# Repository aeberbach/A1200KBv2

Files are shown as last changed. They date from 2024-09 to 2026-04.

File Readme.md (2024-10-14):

A few years ago I made my first Amiga 1200 mechanical keyboard. I did not know at the time about any other efforts that might be underway so I just went ahead and did it. It turned out well and a lot of people built them. Still, there is always a temptation to try and improve something. I was never really happy about the mounting system and the 9U spacebar was a problem, even more so than finding the keycaps that match the Amiga key sizes because modern keyboards went in a different direction.

So here is version 2. At the time of the last keyboard, low-profile keyswitches existed but were hard to find and often could not use MX-stem caps, now it is easier. I'm typing this with a Nuphy Air75 v2 with "Gateron x Nuphy Moss" KS-33 switches and the feel is amazing. There is a lighter variant "Wisteria" and a regular brown tactile option. Blue (clicky) and several variants of linear including red are available too. These switches use a different footprint to standard MX so the PCB had to be redone.

The low profile switches do not come in a 5-pin PCB mount version so a plate is essential. While laser-cut would be amazing I don't have a laser cutter, also that would not be 3-dimensional and would not leave space for the stabilizer wires. To keep it printable on common 3D printers there are multiple pieces to print. I have used eSun matte PLA, a good opaque material that is a good match for an A1200.net case in white or black. The stabilizers mount to the plates, the holes in the PCB underneath are only for clearance. These plates keep the keyswitches perfectly straight during assembly, improve keyboard stiffness, dampen sound and make for a better appearance.

Under the old keyboard a 10x3mm aluminium bar was used to stiffen the whole assembly, running from one side of the case to another sitting on 3d-printed mounts. I want to move that out of the way of expansions under the keyboard. I never noticed a problem with a TF1230 but with a larger accelerator having a heatsink it might be. There is plenty of room for a PiStorm32-lite, by far the fastest and most cost-effective accelerator today.

One thing that hasn't been done is to source a Caps Lock key with a window for the LED. The LED mount is still there and you can put a LED under the switch but I don't know where you can get a windowed keycap for it. The LED section of this keyboard includes a circuit where it will light an alternate LED for power when Caps Lock is active. My keybaord has a green LED for power but that changes to blue when Caps Lock is activated.

If you don't want to use the LED function of this keyboard you can just snip away the top right of the PCB and use the original Amiga 1200 LED PCB. In that case don't bother with LEDs, capacitor, resistors or the inverter chip.

Requirements:
- one PCB (see the 'fab' folder for gerber files, ready to build)
- 96 Gateron KS-33 keyswitches
- 5 Gateron 2U plate-mount low-profile stabilizers
- 1 more Gateron low-profile stabilizer to disassemble - bend your own wire from 1.0mm music wire, available from hobby stores.
- 0805 LEDs: red, green, yellow/orange and blue (or whatever colors you like for the various functions)
- 0805 current-limiting resistor for each LED. Choose a value not less than 300 ohms. If your LEDs are too bright you can use higher values. I found that 500-1k ohms is fine. Your LEDs may vary.
- 0.1uF 0805 decoupling capacitor
- SN74LVC2G04DBVR dual inverter (available Mouser electronics)
- 5-pin dupont housing, pins and ribbon cable to connect LED section to Amiga
- one FFC connector, 32-way RA 1.25mm pitch. Molex 52044-3245 (available Mouser Electronics) or look on AliExpress.
- one FFC ribbon cable, 31-way. Cut one connector from Molex 15168-0400 (available Mouser Electronics) or look on AliExpress.
- Printed left and right plates to house stabilizers and switches on top of PCB (STLs in 3dprint folder)
- Printed left, right and bottom mounts to secure the keyboard in your case (STLs in 3dprint folder)
- various M3 bolts or plastic rivets for assembly
- 96 Amiga keycaps: user Steveed on Amibay recently sorted this out with Signature Plastics and they are perfect. Seems expensive? Not until you spend hours looking for and buying various sets and never end up with a full set. 
 
The cost of all this varies with the cost of PCB manufacture, keyswitches and stabilizers and of course the keycaps. As a very rough guide expect to pay *no less* than about:
- PCB $20
- keyswitches $40
- stabilizers $20
- LEDs and other components $2
- FFC connector and cable $8
- 3D printed parts $10

And assembly will take at least three hours. That's just under $100 in parts alone and does not even count a quality set of keycaps at around $150. (But if you weren't slightly obsessed you probably wouldn't have an Amiga in 2024.)

The license for this keyboard is non-commercial. However if a person has ordered the minimum of 5 PCBs from one of the usual places and wants to offer the extras for sale at near cost that is reasonable.

Thanks to Steveed (Amibay) and to everyone that has supported this project. 

License: CC-BY-NC-SA 4.0

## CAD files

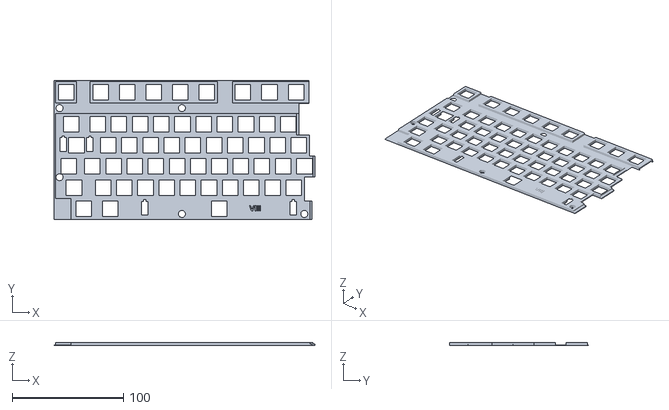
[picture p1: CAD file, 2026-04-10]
3dprint/Keyboard plates/Left Plate (VIII - no connector cut).stl
234.7 x 125.0 x 3.00

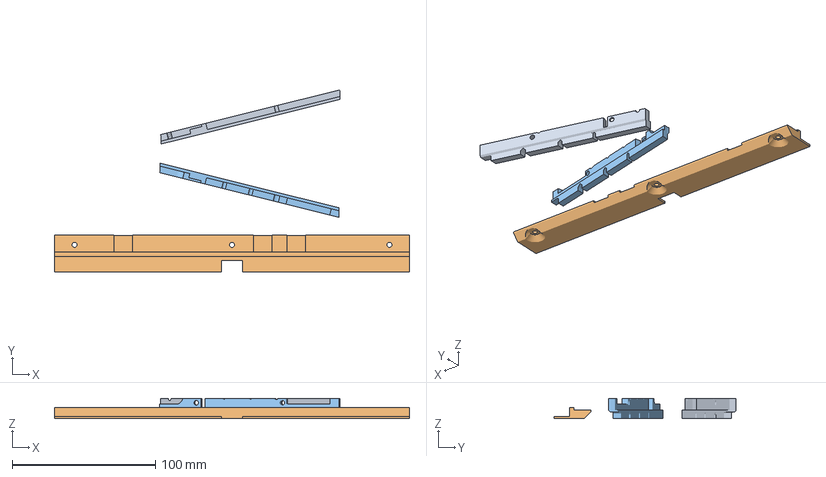
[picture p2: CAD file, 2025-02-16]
3dprint/Production/Prusa Slicer/Left Right Bottom mounts.3mf
248.0 x 127.2 x 14.0 mm
Left mount.stl
Lower mount.stl
Right mount.stl

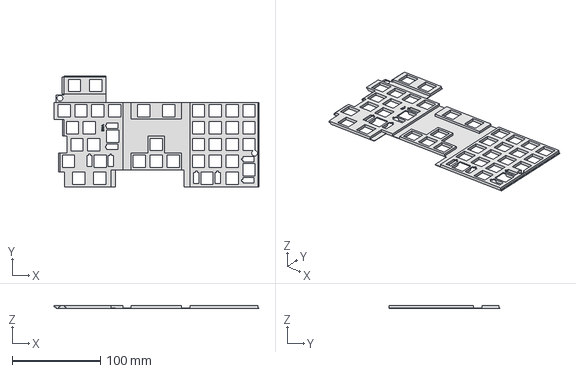
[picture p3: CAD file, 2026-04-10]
3dprint/STEP/Right Plate (VIII).stp
231.7 x 125.0 x 3.00 mm

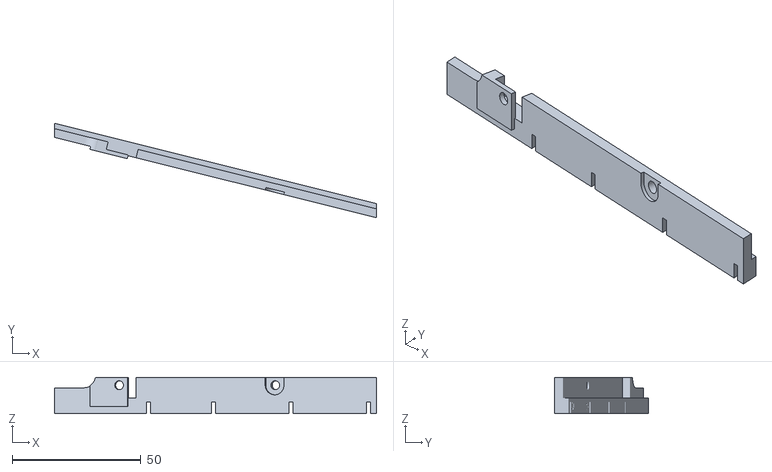
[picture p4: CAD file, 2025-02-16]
3dprint/Production/Commodore Right mount.stl
125.2 x 36.7 x 14.0

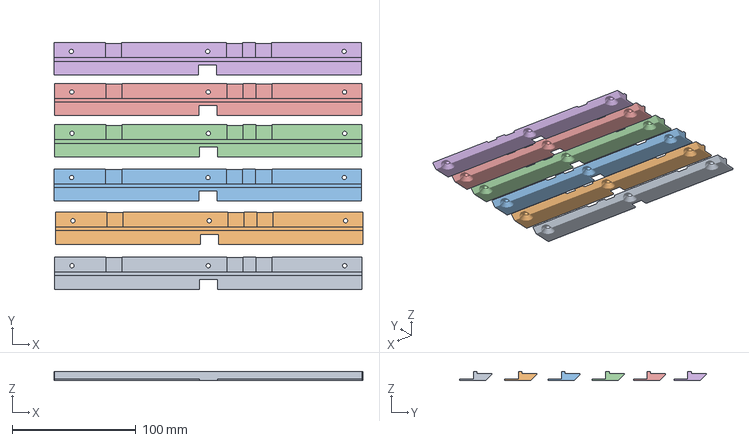
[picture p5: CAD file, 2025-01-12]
3dprint/Production/Prusa Slicer/6 x Lower mount no supports.3mf
249.2 x 198.9 x 7.60 mm

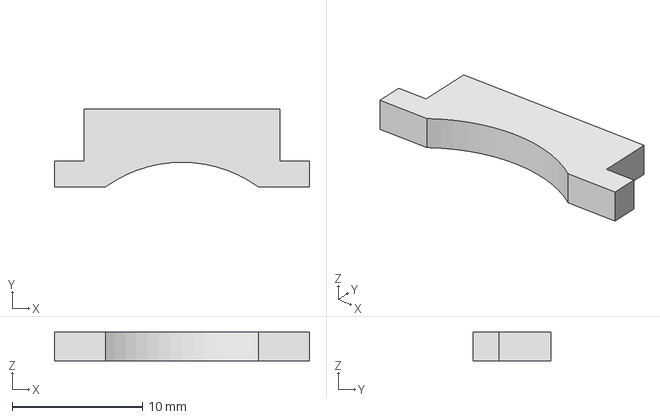
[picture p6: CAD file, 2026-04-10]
3dprint/STEP/Light Pipe A1200Net.stp
19.5 x 6.00 x 2.20 mm

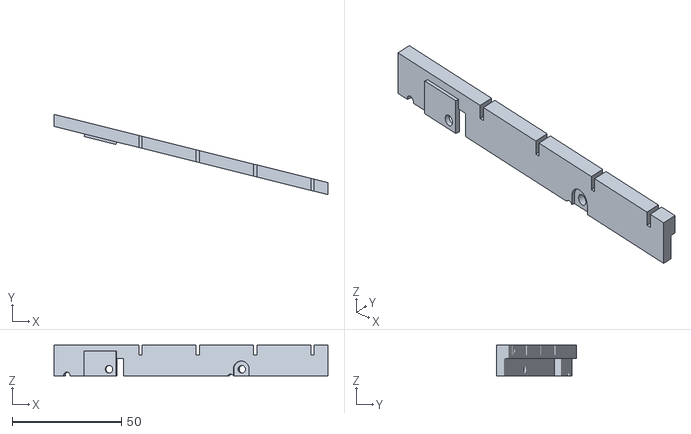
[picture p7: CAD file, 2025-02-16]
3dprint/Production/A1200net Left mount.stl
125.2 x 36.7 x 14.0

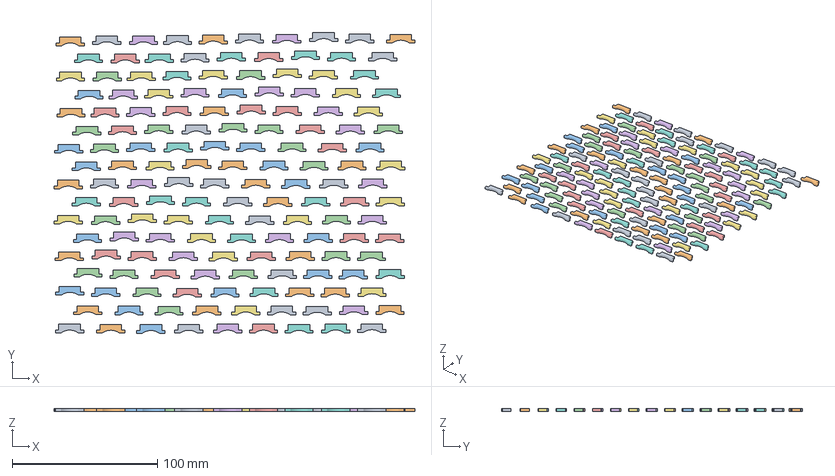
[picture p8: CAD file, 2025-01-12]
3dprint/Production/Prusa Slicer/Many Commodore Light Pipes.3mf
249.0 x 207.3 x 2.20 mm

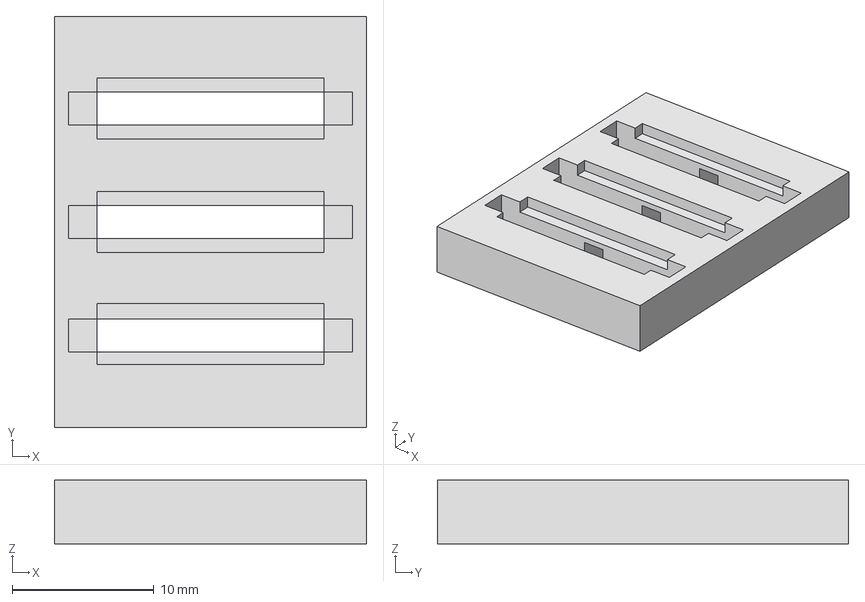
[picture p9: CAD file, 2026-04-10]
3dprint/STEP/Lightpipe shield A1200Net.stp
22.0 x 29.0 x 4.50 mm

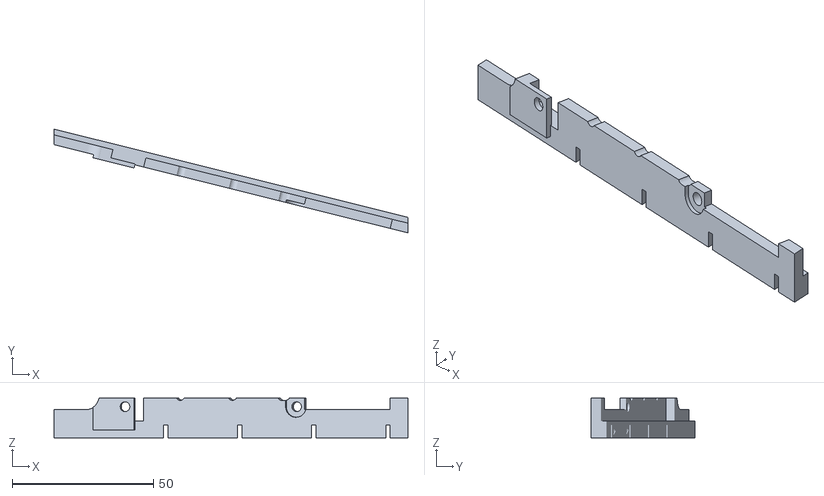
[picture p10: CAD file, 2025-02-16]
3dprint/Production/A1200net Right mount.stl
125.2 x 36.7 x 14.0

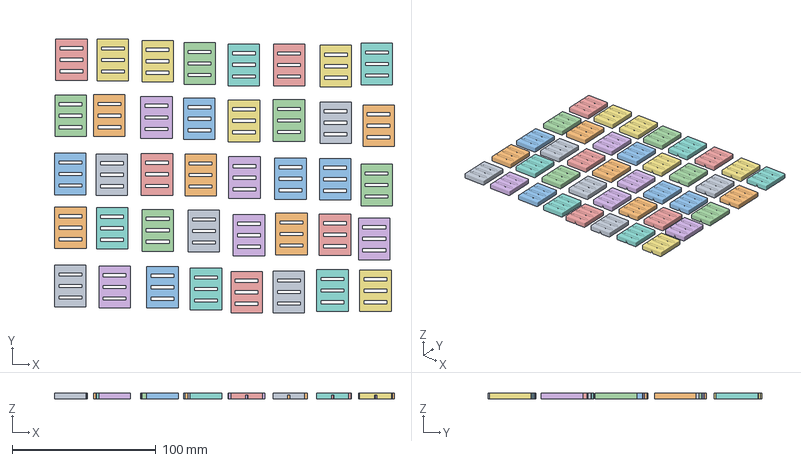
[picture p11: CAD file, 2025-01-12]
3dprint/Production/Prusa Slicer/20 each C= and A1200NET Lightpipe shield.3mf
236.2 x 190.4 x 4.50 mm
A1200NET Lightpipe shield.stl
C= Lightpipe shield.stl

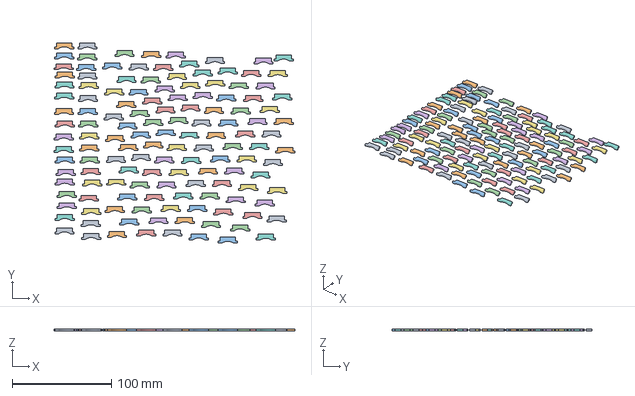
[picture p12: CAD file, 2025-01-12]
3dprint/Production/Prusa Slicer/Many A1200NET Light Pipes.3mf
243.3 x 202.3 x 2.20 mm
A1200NET Light Pipe.stl x 36

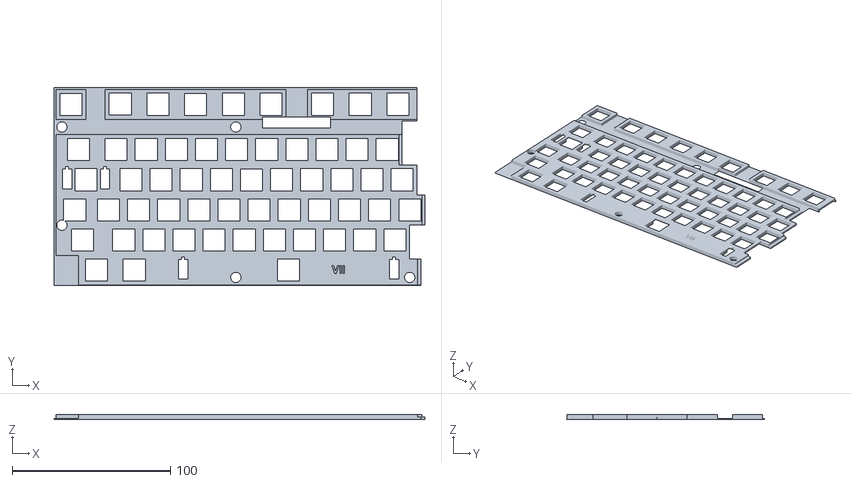
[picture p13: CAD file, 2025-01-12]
3dprint/Production/Common Left Plate (r7 - connector cut).stl
234.7 x 125.0 x 3.00

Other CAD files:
3dprint/Production/Common Left Plate (VIII - no connector cut).stl
3dprint/STEP/Left mount Commodore.stp
3dprint/Production/Commodore Left mount.stl
3dprint/STEP/Left mount A1200net.stp
3dprint/STEP/Right mount Commodore.stp
3dprint/A1200net/Light pipe/Light Pipe modern.ipt
3dprint/A1200net/Light pipe/Lightpipe shield.ipt
3dprint/A1200net/Mounting/A1200net Left mount.ipt
3dprint/A1200net/Mounting/A1200net Right mount.ipt
3dprint/Commodore/Light pipe/Light Pipe Commodore.ipt
3dprint/Commodore/Light pipe/Lightpipe shield.ipt
3dprint/Commodore/Mounting/Commodore Left mount.ipt
3dprint/Commodore/Mounting/Commodore Right mount.ipt
3dprint/Keyboard plates/A1200 Keyboard.iam
3dprint/Keyboard plates/Left Plate (VII - connector cut).ipt
3dprint/Keyboard plates/Left Plate (VIII - no connector cut).ipt
3dprint/Keyboard plates/Left Plate.ipt
3dprint/Keyboard plates/Right Plate.ipt
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

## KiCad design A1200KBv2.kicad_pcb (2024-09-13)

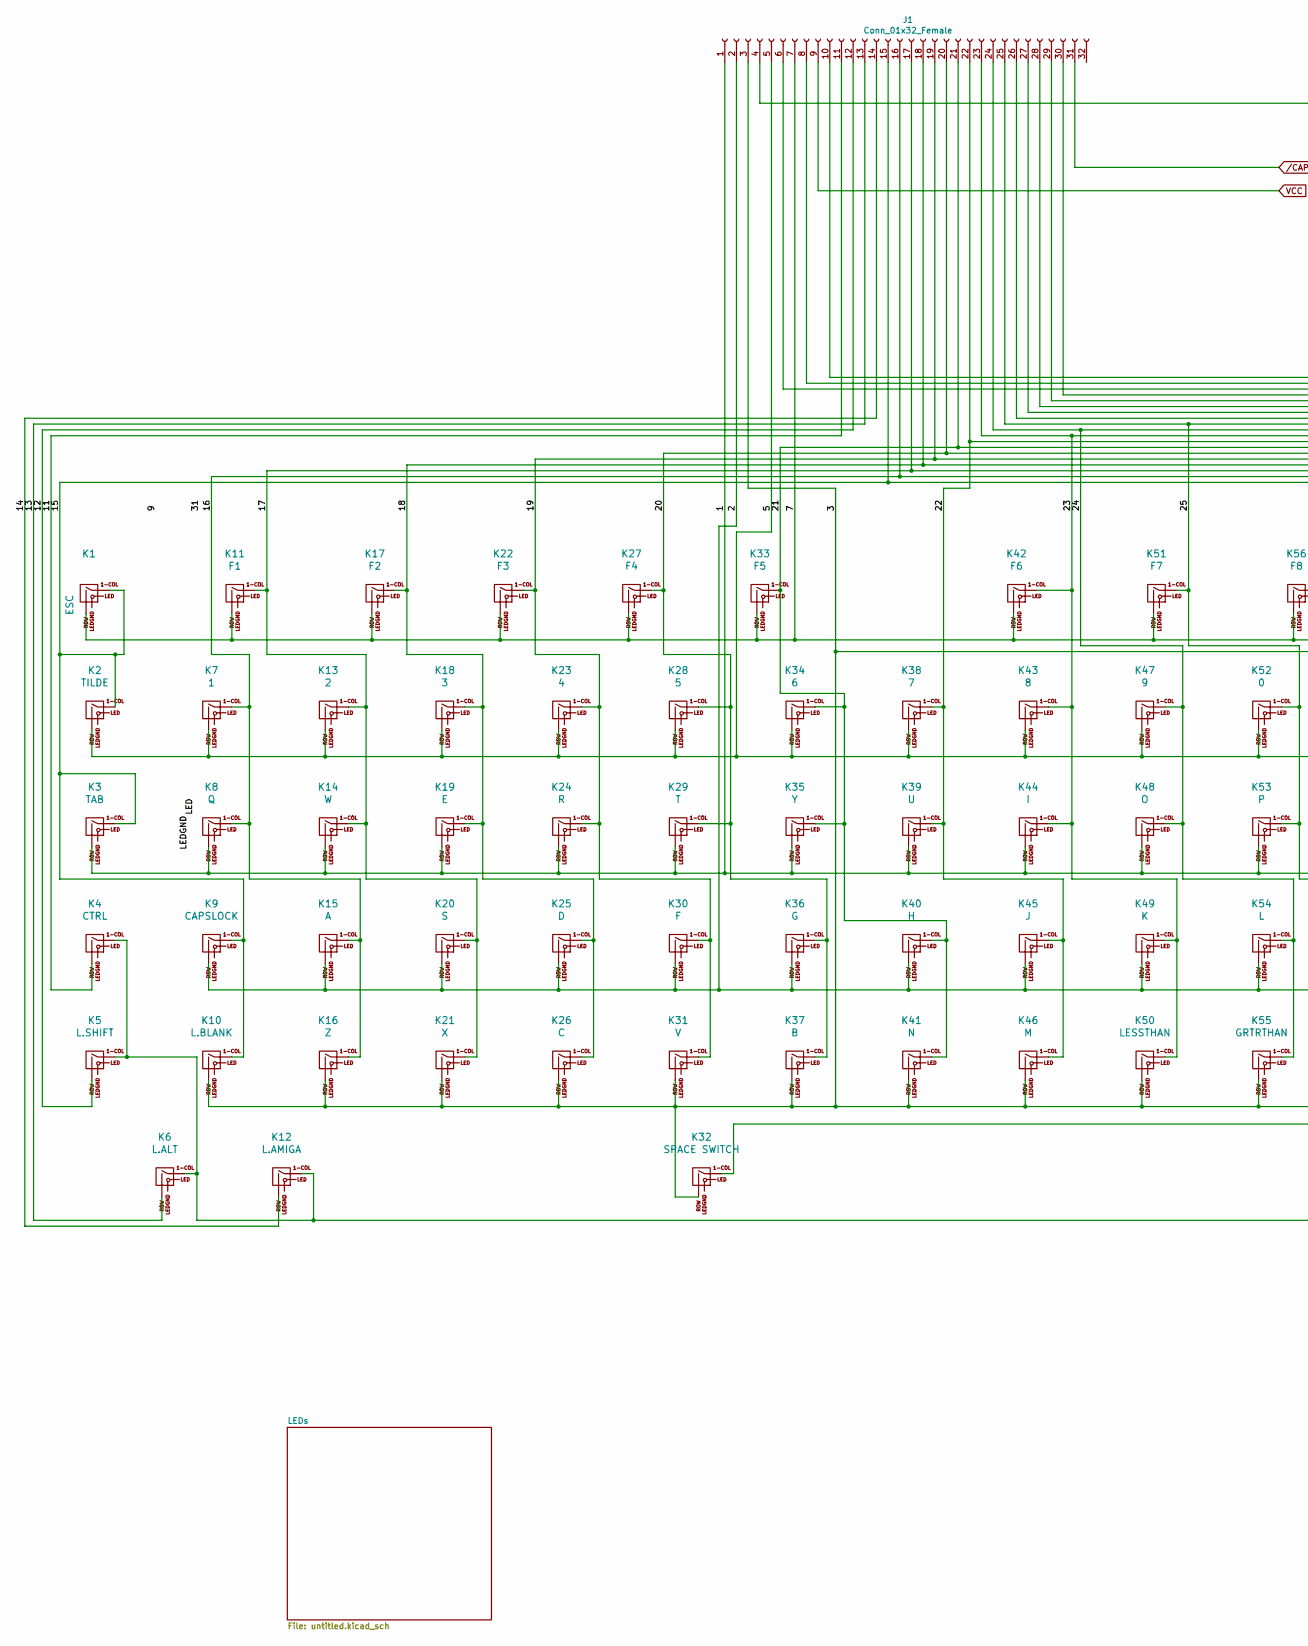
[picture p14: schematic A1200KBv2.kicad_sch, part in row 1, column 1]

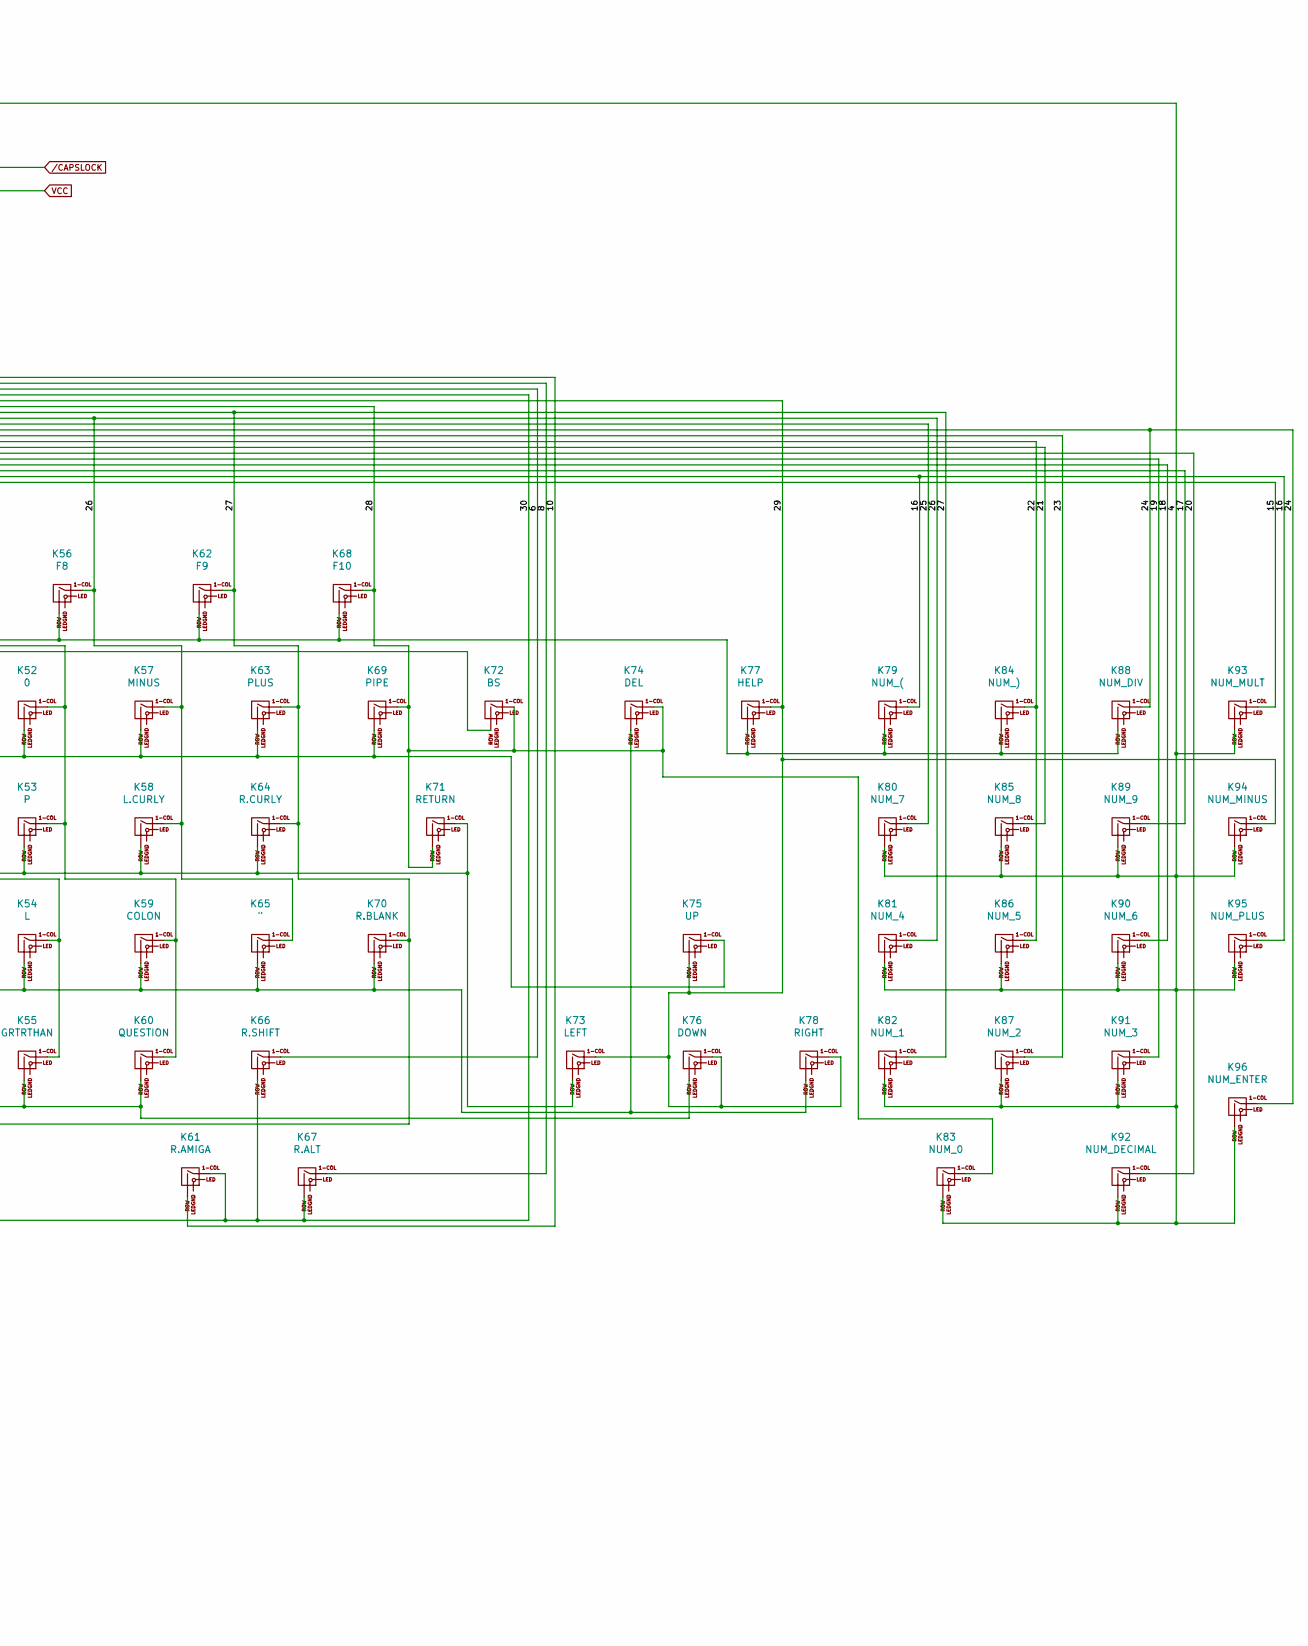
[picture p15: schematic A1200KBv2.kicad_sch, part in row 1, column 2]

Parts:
J1: Conn_01x32_Female; FFC-1.25mm-RA-5204403245
K1: ESC; Gateron-KS33-Solderable-1U
K2: TILDE; Gateron-KS33-Solderable-1.5U
K3: TAB; KS-33-2U-stabilizer
K4: CTRL; Gateron-KS33-Solderable-1.25U
K5: L.SHIFT; Gateron-KS33-Solderable-1.75U
K6: L.ALT; Gateron-KS33-Solderable-1.25U
K7: 1; Gateron-KS33-Solderable-1U
K8: Q; Gateron-KS33-Solderable-1U
K9: CAPSLOCK; Gateron-KS33-Solderable-1U
K10: L.BLANK; Gateron-KS33-Solderable-1U
K11: F1; Gateron-KS33-Solderable-1.25U
K12: L.AMIGA; Gateron-KS33-Solderable-1.25U
K13: 2; Gateron-KS33-Solderable-1U
K14: W; Gateron-KS33-Solderable-1U
K15: A; Gateron-KS33-Solderable-1U
K16: Z; Gateron-KS33-Solderable-1U
K17: F2; Gateron-KS33-Solderable-1.25U
K18: 3; Gateron-KS33-Solderable-1U
K19: E; Gateron-KS33-Solderable-1U
K20: S; Gateron-KS33-Solderable-1U
K21: X; Gateron-KS33-Solderable-1U
K22: F3; Gateron-KS33-Solderable-1.25U
K23: 4; Gateron-KS33-Solderable-1U
K24: R; Gateron-KS33-Solderable-1U
K25: D; Gateron-KS33-Solderable-1U
K26: C; Gateron-KS33-Solderable-1U
K27: F4; Gateron-KS33-Solderable-1.25U
K28: 5; Gateron-KS33-Solderable-1U
K29: T; Gateron-KS33-Solderable-1U
K30: F; Gateron-KS33-Solderable-1U
K31: V; Gateron-KS33-Solderable-1U
K32: SPACE SWITCH; KS-33-8U-space
K33: F5; Gateron-KS33-Solderable-1.25U
K34: 6; Gateron-KS33-Solderable-1U
K35: Y; Gateron-KS33-Solderable-1U
K36: G; Gateron-KS33-Solderable-1U
K37: B; Gateron-KS33-Solderable-1U
K38: 7; Gateron-KS33-Solderable-1U
K39: U; Gateron-KS33-Solderable-1U
K40: H; Gateron-KS33-Solderable-1U
K41: N; Gateron-KS33-Solderable-1U
K42: F6; Gateron-KS33-Solderable-1.25U
K43: 8; Gateron-KS33-Solderable-1U
K44: I; Gateron-KS33-Solderable-1U
K45: J; Gateron-KS33-Solderable-1U
K46: M; Gateron-KS33-Solderable-1U
K47: 9; Gateron-KS33-Solderable-1U
K48: O; Gateron-KS33-Solderable-1U
K49: K; Gateron-KS33-Solderable-1U
K50: LESSTHAN; Gateron-KS33-Solderable-1U
K51: F7; Gateron-KS33-Solderable-1.25U
K52: 0; Gateron-KS33-Solderable-1U
K53: P; Gateron-KS33-Solderable-1U
K54: L; Gateron-KS33-Solderable-1U
K55: GRTRTHAN; Gateron-KS33-Solderable-1U
K56: F8; Gateron-KS33-Solderable-1.25U
K57: MINUS; Gateron-KS33-Solderable-1U
K58: L.CURLY; Gateron-KS33-Solderable-1U
K59: COLON; Gateron-KS33-Solderable-1U
K60: QUESTION; Gateron-KS33-Solderable-1U
K61: R.AMIGA; Gateron-KS33-Solderable-1.25U
K62: F9; Gateron-KS33-Solderable-1.25U
K63: PLUS; Gateron-KS33-Solderable-1U
K64: R.CURLY; Gateron-KS33-Solderable-1U
K65: "; Gateron-KS33-Solderable-1U
K66: R.SHIFT; KS-33-2U-stabilizer
K67: R.ALT; Gateron-KS33-Solderable-1.25U
K68: F10; Gateron-KS33-Solderable-1.25U
K69: PIPE; Gateron-KS33-Solderable-1U
K70: R.BLANK; Gateron-KS33-Solderable-1U
K71: RETURN; KS-33-ISO-2U-stabilizer
K72: BS; Gateron-KS33-Solderable-1U
K73: LEFT; Gateron-KS33-Solderable-1U
K74: DEL; Gateron-KS33-Solderable-1.5U
K75: UP; Gateron-KS33-Solderable-1U
K76: DOWN; Gateron-KS33-Solderable-1U
K77: HELP; Gateron-KS33-Solderable-1.5U
K78: RIGHT; Gateron-KS33-Solderable-1U
K79: NUM_(; Gateron-KS33-Solderable-1U
K80: NUM_7; Gateron-KS33-Solderable-1U
K81: NUM_4; Gateron-KS33-Solderable-1U
K82: NUM_1; Gateron-KS33-Solderable-1U
K83: NUM_0; KS-33-2U-stabilizer
K84: NUM_); Gateron-KS33-Solderable-1U
K85: NUM_8; Gateron-KS33-Solderable-1U
K86: NUM_5; Gateron-KS33-Solderable-1U
K87: NUM_2; Gateron-KS33-Solderable-1U
K88: NUM_DIV; Gateron-KS33-Solderable-1U
K89: NUM_9; Gateron-KS33-Solderable-1U
K90: NUM_6; Gateron-KS33-Solderable-1U
K91: NUM_3; Gateron-KS33-Solderable-1U
K92: NUM_DECIMAL; Gateron-KS33-Solderable-1U
K93: NUM_MULT; Gateron-KS33-Solderable-1U
K94: NUM_MINUS; Gateron-KS33-Solderable-1U
K95: NUM_PLUS; Gateron-KS33-Solderable-1U
K96: NUM_ENTER; KS-33-2U-stabilizer

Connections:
/1: J1.1, K3.2 (ROW), K8.2 (ROW), K14.2 (ROW), K19.2 (ROW), K24.2 (ROW), K29.2 (ROW), K35.2 (ROW), K39.2 (ROW), K44.2 (ROW), K48.2 (ROW), K53.2 (ROW), K58.2 (ROW), K64.2 (ROW), K71.1 (COL), K73.2 (ROW)
/2: J1.2, K9.2 (ROW), K15.2 (ROW), K20.2 (ROW), K25.2 (ROW), K30.2 (ROW), K36.2 (ROW), K40.2 (ROW), K45.2 (ROW), K49.2 (ROW), K54.2 (ROW), K59.2 (ROW), K65.2 (ROW), K70.2 (ROW), K74.2 (ROW), K78.2 (ROW)
/3: J1.3, K10.2 (ROW), K16.2 (ROW), K21.2 (ROW), K26.2 (ROW), K31.2 (ROW), K32.2 (ROW), K37.2 (ROW), K41.2 (ROW), K46.2 (ROW), K50.2 (ROW), K55.2 (ROW), K60.2 (ROW), K72.2 (ROW), K76.2 (ROW)
/4: J1.4, K80.2 (ROW), K81.2 (ROW), K82.2 (ROW), K83.2 (ROW), K85.2 (ROW), K86.2 (ROW), K87.2 (ROW), K89.2 (ROW), K90.2 (ROW), K91.2 (ROW), K92.2 (ROW), K93.2 (ROW), K94.2 (ROW), K95.2 (ROW), K96.2 (ROW)
/5: J1.5, K2.2 (ROW), K7.2 (ROW), K13.2 (ROW), K18.2 (ROW), K23.2 (ROW), K28.2 (ROW), K34.2 (ROW), K38.2 (ROW), K43.2 (ROW), K47.2 (ROW), K52.2 (ROW), K57.2 (ROW), K63.2 (ROW), K69.2 (ROW), K75.1 (COL)
/6: J1.6, K66.1 (COL)
/7: J1.7, K1.2 (ROW), K11.2 (ROW), K17.2 (ROW), K22.2 (ROW), K27.2 (ROW), K33.2 (ROW), K42.2 (ROW), K51.2 (ROW), K56.2 (ROW), K62.2 (ROW), K68.2 (ROW), K77.2 (ROW), K79.2 (ROW), K84.2 (ROW), K88.2 (ROW)
/8: J1.8, K67.1 (COL)
/10: J1.10, K61.2 (ROW)
/11: J1.11, K4.2 (ROW)
/12: J1.12, K5.2 (ROW)
/13: J1.13, K6.2 (ROW)
/14: J1.14, K12.2 (ROW)
/15: J1.15, K1.1 (COL), K2.1 (COL), K3.1 (COL), K9.1 (COL), K10.1 (COL), K93.1 (COL)
/16: J1.16, K7.1 (COL), K8.1 (COL), K15.1 (COL), K16.1 (COL), K79.1 (COL), K95.1 (COL)
/17: J1.17, K11.1 (COL), K13.1 (COL), K14.1 (COL), K20.1 (COL), K21.1 (COL), K89.1 (COL)
/18: J1.18, K17.1 (COL), K18.1 (COL), K19.1 (COL), K25.1 (COL), K26.1 (COL), K90.1 (COL)
/19: J1.19, K22.1 (COL), K23.1 (COL), K24.1 (COL), K30.1 (COL), K31.1 (COL), K91.1 (COL)
/20: J1.20, K27.1 (COL), K28.1 (COL), K29.1 (COL), K36.1 (COL), K37.1 (COL), K92.1 (COL)
/21: J1.21, K33.1 (COL), K34.1 (COL), K35.1 (COL), K40.1 (COL), K41.1 (COL), K85.1 (COL)
/22: J1.22, K38.1 (COL), K39.1 (COL), K45.1 (COL), K46.1 (COL), K84.1 (COL), K86.1 (COL)
/23: J1.23, K42.1 (COL), K43.1 (COL), K44.1 (COL), K49.1 (COL), K50.1 (COL), K87.1 (COL)
/24: J1.24, K47.1 (COL), K48.1 (COL), K54.1 (COL), K55.1 (COL), K88.1 (COL), K96.1 (COL)
/25: J1.25, K51.1 (COL), K52.1 (COL), K53.1 (COL), K59.1 (COL), K60.1 (COL), K80.1 (COL)
/26: J1.26, K56.1 (COL), K57.1 (COL), K58.1 (COL), K65.1 (COL), K81.1 (COL)
/27: J1.27, K32.1 (COL), K62.1 (COL), K63.1 (COL), K64.1 (COL), K70.1 (COL), K82.1 (COL)
/28: J1.28, K68.1 (COL), K69.1 (COL), K71.2 (ROW), K72.1 (COL), K74.1 (COL), K83.1 (COL)
/29: J1.29, K73.1 (COL), K75.2 (ROW), K76.1 (COL), K77.1 (COL), K78.1 (COL), K94.1 (COL)
/30: J1.30, K4.1 (COL), K5.1 (COL), K6.1 (COL), K12.1 (COL), K61.1 (COL), K66.2 (ROW), K67.2 (ROW)
VCC: J1.9; also elsewhere on the board
/CAPSLOCK: J1.31; also elsewhere on the board

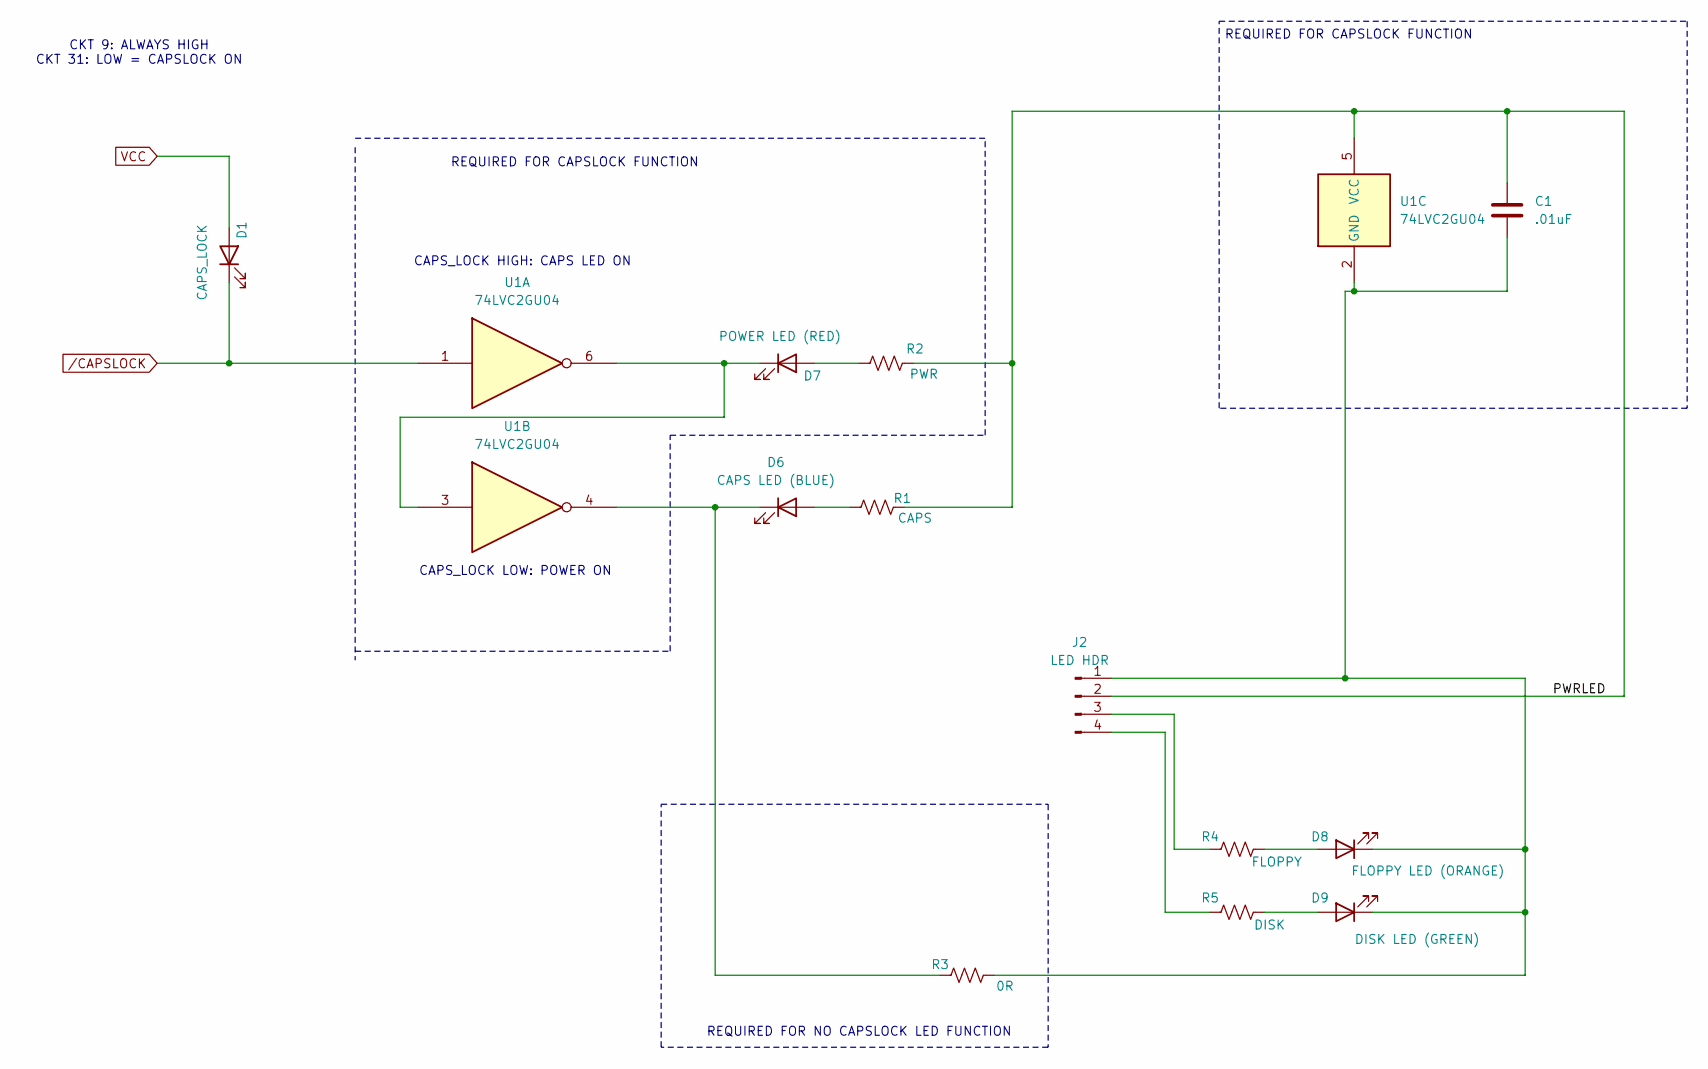
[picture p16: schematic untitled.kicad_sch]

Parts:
C1: .01uF; C_0805_2012Metric_Pad1.18x1.45mm_HandSolder
D1: CAPS_LOCK; LED_0805_2012Metric
D6: CAPS LED (BLUE); LED_0805_2012Metric
D7: POWER LED (RED); LED_0805_2012Metric
D8: FLOPPY LED (ORANGE); LED_0805_2012Metric
D9: DISK LED (GREEN); LED_0805_2012Metric
J2: LED HDR; PinHeader_1x04_P2.54mm_Vertical
R1: CAPS; R_0805_2012Metric_Pad1.20x1.40mm_HandSolder
R2: PWR; R_0805_2012Metric_Pad1.20x1.40mm_HandSolder
R3: 0R; R_0805_2012Metric_Pad1.20x1.40mm_HandSolder
R4: FLOPPY; R_0805_2012Metric_Pad1.20x1.40mm_HandSolder
R5: DISK; R_0805_2012Metric_Pad1.20x1.40mm_HandSolder
U1: 74LVC2GU04; SOT-23-6

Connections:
/LEDs/PWRLED: C1.1, J2.2, R1.2, R2.2, U1.5 (VCC)
unnamed: D6.2 (A), R1.1
unnamed: D6.1 (K), R3.1, U1.4
unnamed: D7.2 (A), R2.1
unnamed: D7.1 (K), U1.3, U1.6
unnamed: D8.2 (A), R4.2
unnamed: C1.2, D8.1 (K), D9.1 (K), J2.1, R3.2, U1.2 (GND)
unnamed: D9.2 (A), R5.2
unnamed: J2.3, R4.1
unnamed: J2.4, R5.1
VCC: D1.2 (A); also elsewhere on the board
/CAPSLOCK: D1.1 (K), U1.1; also elsewhere on the board

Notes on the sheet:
CAPS_LOCK LOW: POWER ON
CKT 9: ALWAYS HIGH CKT 31: LOW = CAPSLOCK ON
REQUIRED FOR CAPSLOCK FUNCTION
CAPS_LOCK HIGH: CAPS LED ON
REQUIRED FOR NO CAPSLOCK LED FUNCTION

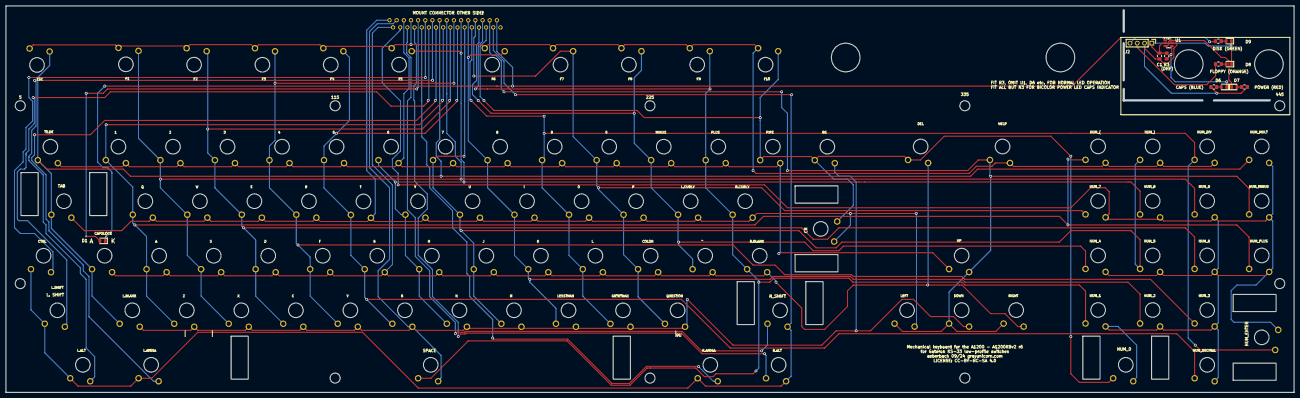
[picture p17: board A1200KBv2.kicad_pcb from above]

Board: 2 copper layers, 450.0 x 135.0 mm, 110 parts (1 on the bottom side), 41 nets.

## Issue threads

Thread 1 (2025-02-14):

Keyboard stabiliser cuts not large enough?

aeberbach, 2025-02-14:
I have noticed the right keyboard stabilizer cut in the PCB seems too close the switch so that the stabilizer can be bent slightly when the keyboard plate is in place. These PCB cuts are not at all critical and could be extended 0.5-1mm on both sides, which would make an easier fit and ensure no space bar return interference.

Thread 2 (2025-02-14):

"Universal" side rails not quite universal for C= case

aeberbach, 2025-02-14:
A couple of people have reported that the current universal side rails do not fit well in a Commodore case. The lowest protruding tab is getting in the way. This is slightly more complicated than it needs to be, it would support just as well if both tabs were removed. The three remaining slots are enough to locate the keyboard accurately in the vertical direction.

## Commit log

2024-06-20 rev 1 of new A1200kb for KS-33 switches
    [A1200KBv2-B_Cu.gbr, A1200KBv2-B_Mask.gbr, A1200KBv2-B_Paste.gbr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]
2024-06-21 New version with new footprints; low-profile plate stabilizers
    [A1200KBv2-B_Cu.gbr, A1200KBv2-B_Mask.gbr, A1200KBv2-B_Paste.gbr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]
2024-07-08 fab 9/7/24 A1200 for KS-33 A1200.net case
    [A1200KBv2-B_Cu.gbr, A1200KBv2-B_Mask.gbr, A1200KBv2-B_Paste.gbr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]
2024-08-07 remove junk files
    [A1200KBv2-brd.dxf, A1200KBv2.dwg, PCB Locations.ods]
2024-08-07 arrange LEDs
    [A1200KBv2-B_Cu.gbr, A1200KBv2-B_Mask.gbr, A1200KBv2-B_Paste.gbr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]
2024-08-22 Plates for final r5
    [A1200 Keyboard.iam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]
2024-09-02 10mm higher; keyboard connector out of the way
    [A1200KBv2.kicad_pcb]
2024-09-02 Revert "10mm higher; keyboard connector out of the way"
    This reverts commit 7b7d121ea175ab04d54ee7bb06e71218aa1ce09d.
    [A1200KBv2.kicad_pcb]
2024-09-02 v6 (keyboard connector out of the way, 135mm high)
    [A1200KBv2-B_Cu.gbr, A1200KBv2-B_Mask.gbr, A1200KBv2-B_Paste.gbr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]
2024-09-02 v6 as manufactured
    [A1200KBv2.kicad_pcb]
2024-09-03 Move some parts into production folder
    [A1200net Light Pipe.stl, A1200net Lightpipe shield.stl, Commodore Lightpipe shield.stl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]
2024-09-13 in production V6
    [Light Pipe Commodore.ipt, Light Pipe Commodore.stl, Light Pipe Modern.stl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]
2024-09-13 r6 for FFC connector above F keys
    [A1200 Keyboard.iam, Left Plate v6.stl, Left Plate.ipt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]
2024-10-06 Revise right pate again - R. shift key smooth
    [Right Plate r6.stl, Right Plate r7.stl, Right Plate r8.stl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]
2024-10-14 Consistent naming STL
    [A1200KBv2r5 A1200net mounts 8x L and R.3mf, A1200KBv2r5 Commodore mounts 8x L and R.3mf, A1200KBv2r5 Right Plate.3mf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]
2024-11-03 sort 3D print files
    [A1200KBv2r5.ipt, A1200net Left mount.stl, A1200net Right mount.stl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]
2025-01-12 A1200KBV2 reorg files and prod slicer files
    [20 each C= and A1200NET Lightpipe shield.3mf, 21 x Common Right mount no supports.3mf, 26 x Common Left mount no supports.3mf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]
2025-02-16 remove lower tabs on left and right mounts
    [21 x Common Right mount no supports.3mf, 26 x Common Left mount no supports.3mf, Left Right Bottom mounts.3mf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]
2025-02-16 replace universal mnounts with dedicated for now
    [A1200net Left mount.ipt, A1200net Right mount.ipt, Commodore Left mount.ipt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]
2025-02-16 Replace Commodore/A1200 left and right mounts in production folder
    [A1200net Left mount.0004.ipt, A1200net Left mount.ipt, A1200net Left mount.stl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]
2025-03-10 no special changes
    [A1200KBv2r5.step, Left mount.0004.ipt, Lower mount.0007.ipt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]
2026-04-10 Commit STEP
    [Common Left Plate (VIII - no connector cut).stl, Left Plate (VIII - no connector cut).ipt, Left Plate (VIII - no connector cut).stl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]
